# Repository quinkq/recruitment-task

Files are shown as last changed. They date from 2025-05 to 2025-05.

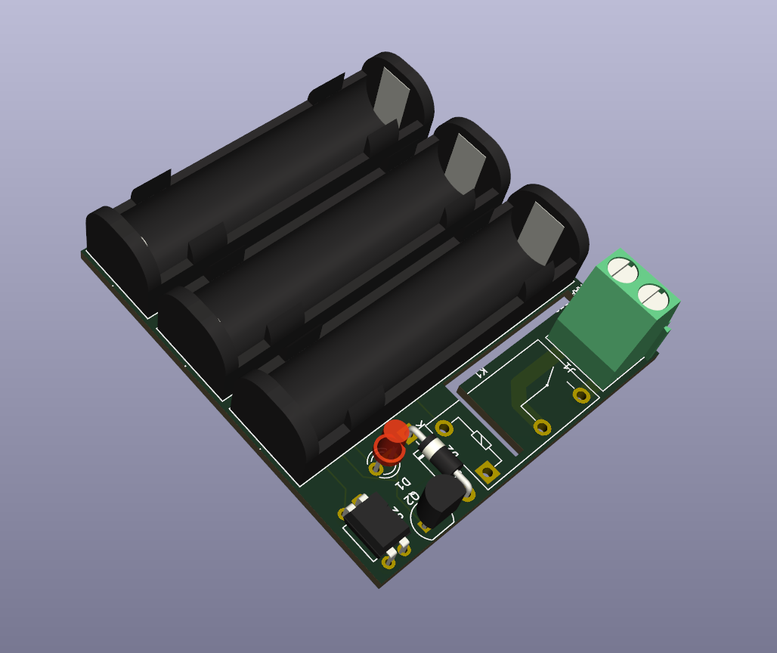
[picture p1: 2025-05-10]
hardware schematics/PCB.png

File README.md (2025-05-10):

Compact, battery-powered electronic device that controls a relay for switching an 110/240 VAC 6A load.

I. Description
This circuit is a compact battery-powered system based on an ATmega328P microcontroller that can monitor battery
voltage, control a relay, and provide user interaction through buttons and status indicators. The design emphasizes low
power consumption with a voltage regulator to provide stable power to the microcontroller.
Power Supply
- Three 1.5V AAA batteries connected in series provide 4.5V input power
- MCP1700 low-dropout regulator (U3) converts the battery voltage to a stable 3.3V for the microcontroller
- Decoupling capacitors (C1, C2, C3, C7) ensure clean power delivery
Microcontroller
- ATmega328P in TQFP package (U1) serves as the main controller
- Reset circuit with push button (SW2) and pull-up resistor (R7) allows for manual resets
- Analog input connected to a voltage divider monitors battery level
- Digital I/O pins control external components
Output Control
- Relay (K1) allows switching of external high-voltage/high-current loads
- Optocoupler (PC817, U2) provides electrical isolation between the microcontroller and relay driver
- NPN transistor (2N3904, Q2) amplifies the control signal to drive the relay coil
- Protection diode (1N4007, D2) prevents inductive kickback when the relay is de-energized
- LED indicator (D1) provides visual status feedback
User Interface
- Push button input (SW1) allows for user interaction
- LED output provides visual feedback on system status

II. Control: Microcontroller ATMEL ATmega328P
1. Low Power
- Active mode: ~5mA at 3.3V, 8MHz
- Power-down sleep mode: <1μA (with proper power management)
- If running at 1MHz, it can drop active current below 1mA.
- Sleep modes allow long battery life
2. Simple and Cheap
- Readily available and has a huge ecosystem of code and libraries.
- Modular
- Cost-efficient.
3. Adequate Performance for the Task
- 10-bit ADC sufficient for battery voltage monitoring.
- Computing power more than sufficient for current project requirements.
- Enough flash and RAM (32KB Flash / 2KB RAM) for basic sensor logging and control logic.
4. Ease of Development and Debugging
- Arduino-compatible for quick prototyping.
- Analog and digital pin flexibility (for sensing battery, controlling relays, etc.) - makes it great choice for further
project adaptations.
- AVR ISP / UPDI flashing - can be pre-programmed before soldering.
In current configuration assuming pulling up unused digital pins and running by using internal oscillator.
Considerations:
STM32L0 series (for example STM32L011K or other low power variant) is a very strong contender for an alternative MCU.
It could offer substantial processing power increase (modern Cortex-M0 32-bit processor), allow for easy integrations if
for example wireless communication was considered for the future, but also opens possibility for even cheaper
components when ordering in bulk/partnering with STM.
If low power chip with integrated Bluetooth LE was a requirement from the start, then nRF52832 is another great option.
Employing wireless functionality in any of these variants would make for an attractive product to compete with SONOFF
products for example.

III. Power source: 3 x AAA batteries + LDO regulator
Due to the requirement of having battery powered controlling device, that will be inherently ineffective when driving a
power-hungry coil of the relay, the simplest solution has been chosen in form of using 3 x AAA batteries. They are
designed to be connected in series, in order to boost voltage to 4.5V, which is then shifted down to MCU and relay
compatible 3.3V level using LDO regulator. Since it’s unlikely that any compact battery will be able to power circuit
satisfying the requirements for more than 7 days, choosing AAA battery was crucial due to ease of their replacement.
1. High popularity and availability
2. Very easy to replace
3. Relatively high capacity, but dependent on the quality of batteries (about 1200 mAh)
4. Enables possibility to commercially distribute the device without batteries (passing this requirement on to the
consumer)
Considerations:
Since this project would likely be used as a device used for switching mains power supply, then most logical would be
adding a switching power supply and filtering its output to power both MCU and relay coil, instead of using batteries.
For more premium devices (relay switching noise unwanted) double MOSFET (totem pole) configuration would be a
great solution, that could be actually run with batteries. If heat dissipation or low volume were critical factors, then it
would still be possible, but would require choosing more high-end MOSFET with lower Rds(on).

IV. Components, calculations, values.
All components have been chosen with the goal of being easily sourceable and replaceable. With further testing
adjustments towards limiting optocoupler and transistor current could and should be made, as that would allow
further energy savings.
Capacitors: All ceramic for decoupling purposes, values according to chip manufacturer’s guidelines.
Resistors: Same principle with exception of:
R2 = 1000 Ohms = 3.3 V / 0.0025 A – limiting current to about 2.5 mA, enough for BJT transistor operation.
R3 = 560 Ohms = 3.3 V / 0.005 A – goal of limiting opto-coupler current down to about 5 mA, to keep small overhead in
case of PC817 current transfer ratio drops.
R4 = 150 Ohms = 3.3 V – 1.2 V / 0.0025 A – goal to maintain about 15mA LED current, assuming standard diode’s 1.2 Vf.
Dependent on final components.
R5 = 36 kOhm R6 = 100kOhm – typical voltage divider for ADC that is designed to take 3.3V as a reference (AREF pin
grounded with C4 capacitor).
Vadc = Vbat × R6/ (R5+R6)
3.3V = 4.5V x R2 / (R5+R6)
R6 / (R5+R6) = 3.3V / 4.5V = 0.733
R6 = 0.733 × (R5+R6)
Designating R6 to be 100 kOhm and solving for R5:
R5 = (100 kOhm / 0.733) − 100kΩ ≈ 36 kOhm

V. Battery life
Assuming high current draw in 30% of the time - device idling (50% of the time) and off time when toggling relay.
ATmega328P Current Consumption
Active Mode (when relay is ON): ~5mA
Sleep Mode (when relay is OFF): ~0.1mA
Relay Consumption
ON (30% of the time): ~20mA – nominal relay current ~ 70mA
OFF (70% of the time): 0mA
Other consumers
Optocoupler + transistor sinking: 7.5mA
Average Current Calculation
(5mA+20mA+7.5mA) × 30% + (0.1mA) × 70% =
= (32.5mA × 30%) + (0.1mA × 70%) =
= 9.75mA + 0.07mA = 9.82 mA
Battery Life (1200mAh AAA in series)
1200 mAh ÷ (~9.82mA) = 122 hours = about 5 days

VI. Costs
Details in BOM.csv.
Estimate for making 5 pieces:
10,16 USD
Estimate for making 1000 pieces:
4,20 USD

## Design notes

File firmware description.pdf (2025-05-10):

## Programming environment:

### VS Code + PlatformiO

Deciding factors:

PlatformIO IDE is a powerful and feature-rich development environment for a larger project that uses the Arduino framework but supports a wider range of microcontroller platforms and development boards, helps maintain better project structure and code maintainability by allowing for proper C++ conventions (separate .h and .cpp files), and offering more efficient debugging and tooling.

## Logic description:

### 1. Setup (setup())

- Initializes serial communication for debugging.
- Configures GPIO pins for button, relay, LED, and battery voltage monitoring.
- Sets button interrupt to wake the device on a press.
- Enters sleep mode immediately after initialization.

### 2. Main Loop (loop())

- Wakes up on button press and processes it (handleButton()).
- If device is ON:
- Checks battery voltage every 5 seconds.
- Toggles relay at the set frequency.
- Updates LED indicator.
- If device is OFF, it enters sleep mode after 500ms.

### 3. Button Handling (handleButton())

- Uses debounce logic to ensure stable button readings.
- Short press toggles the device ON/OFF.
- Long press:
- Adjusts the relay toggle frequency.
- If the button remains pressed, keeps changing frequency at set intervals.

### 4. Changing Relay Frequency (changeFrequency())

- Cycles relay toggle frequency between 1s and 10s.
- Automatically reverses direction when reaching limits (10s -> 9s -> ... -> 1s -> 2s ...).
- LED briefly flashes to indicate a frequency change.

### 5. Relay Toggling (toggleRelay())

- Switches the relay ON/OFF at set intervals.
- Prints status to serial monitor for debugging.

### 6. Battery Monitoring (checkBatteryVoltage())

- Reads voltage using an analog pin.
- Converts ADC value to actual voltage using a voltage divider.
- If voltage < 3.0V, sets lowBatteryDetected = true and starts rapid LED blinking.

### 7. Sleep Mode (enterPowerSavingMode())

- Disables ADC to reduce power consumption.
- Uses SLEEP_MODE_PWR_DOWN to enter sleep.
- Execution halts until button press wakes it up.

### 8. Wake-up Handling (exitPowerSavingMode())

- Re-enables ADC after waking up.
- Ensures the system resumes normal operation.

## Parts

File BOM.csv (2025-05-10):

Reference | Qty | Value | Footprint | Price (1pc) | Sum for (1pc price) | Price (1000pcs) | Sum for (1000pc price) [USD] | Datasheet
AAA-BT1,AAA-BT2,AAA-BT3 | 3 | 1.5V | Battery:BatteryHolder_Keystone_2466_1xAAA | 0,52 | 0,52 | 0,333 | 0,333 | ~
C1,C4,C7 | 3 | 0.1µF | Capacitor_SMD:C_0805_2012Metric | 0,004 | 0,012 | 0,0036 | 0,0108 | ~
C2,C3 | 2 | 1µF | Capacitor_SMD:C_0805_2012Metric | 0,004 | 0,008 | 0,0036 | 0,0072 | ~
D1 | 1 | LED | LED_THT:LED_D3.0mm_FlatTop | 0,02 | 0,02 | 0,018 | 0,018 | ~
D2 | 1 | 1N4007 | Diode_THT:D_DO-41_SOD81_P10.16mm_Horizontal | 0,008 | 0,008 | 0,005 | 0,005 | http://www.vishay.com/docs/88503/1n4001.pdf
J1 | 1 | Screw_Terminal_01x02 | TerminalBlock_Phoenix:TerminalBlock_Phoenix_MKDS-1,5-2_1x02_P5.00mm_Horizontal | 0,0894 | 0,0894 | 0,0591 | 0,0591 | ~
K1 | 1 | G5Q-1A | Relay_THT:Relay_SPST_Omron-G5Q-1A | 0,9036 | 0,9036 | 0,5468 | 0,5468 | https://www.omron.com/ecb/products/pdf/en-g5q.pdf
Q2 | 1 | 2N3904 | Package_TO_SOT_THT:TO-92_Inline | 0,0115 | 0,0115 | 0,0077 | 0,0077 | https://www.onsemi.com/pub/Collateral/2N3903-D.PDF
R2 | 1 | 1k | Resistor_SMD:R_0805_2012Metric | 0,0018 | 0,0018 | 0,0014 | 0,0014 | ~
R3 | 1 | 470 | Resistor_SMD:R_0805_2012Metric | 0,0018 | 0,0018 | 0,0014 | 0,0014 | ~
R4 | 1 | 150 | Resistor_SMD:R_0805_2012Metric | 0,0018 | 0,0018 | 0,0014 | 0,0014 | ~
R5 | 1 | 36k | Resistor_SMD:R_0805_2012Metric | 0,0018 | 0,0018 | 0,0014 | 0,0014 | ~
R6 | 1 | 100k | Resistor_SMD:R_0805_2012Metric | 0,0018 | 0,0018 | 0,0014 | 0,0014 | ~
R7,R8 | 2 | 10k | Resistor_SMD:R_0805_2012Metric | 0,0018 | 0,0036 | 0,0014 | 0,0028 | ~
SW1 | 1 | SW_Push | Button_Switch_SMD:SW_SPST_CK_RS282G05A3 | 0,796 | 0,796 | 0,2918 | 0,2918 | ~
SW2 | 1 | SW_Push | Button_Switch_SMD:SW_SPST_PTS647_Sx70 | 0,1925 | 0,1925 | 0,1243 | 0,1243 | ~
U1 | 1 | ATmega328P-A | Package_QFP:TQFP-32_7x7mm_P0.8mm | 2,1871 | 2,1871 | 1,5494 | 1,5494 | http://ww1.microchip.com/downloads/en/DeviceDoc/ATmega328_P%20AVR%20MCU%20with%20picoPower%20Technology%20Data%20Sheet%2040001984A.pdf
U2 | 1 | PC817 | Package_DIP:DIP-4_W7.62mm | 0,0341 | 0,0341 | 0,0185 | 0,0185 | http://www.soselectronic.cz/a_info/resource/d/pc817.pdf
U3 | 1 | MCP1700x-330xxTT | Package_TO_SOT_SMD:SOT-23 | 0,3705 | 0,3705 | 0,2257 | 0,2257 | http://ww1.microchip.com/downloads/en/DeviceDoc/20001826D.pdf
PCB Manufacturing | 1 |  |  | 5 | 5 | 1 | 1
 |  |  |  |  | Estimate for 5 pcs |  | Estimate for 1000 pcs
 |  |  |  | Total Sum | 10,1683 | USD | 4,2071 | USD

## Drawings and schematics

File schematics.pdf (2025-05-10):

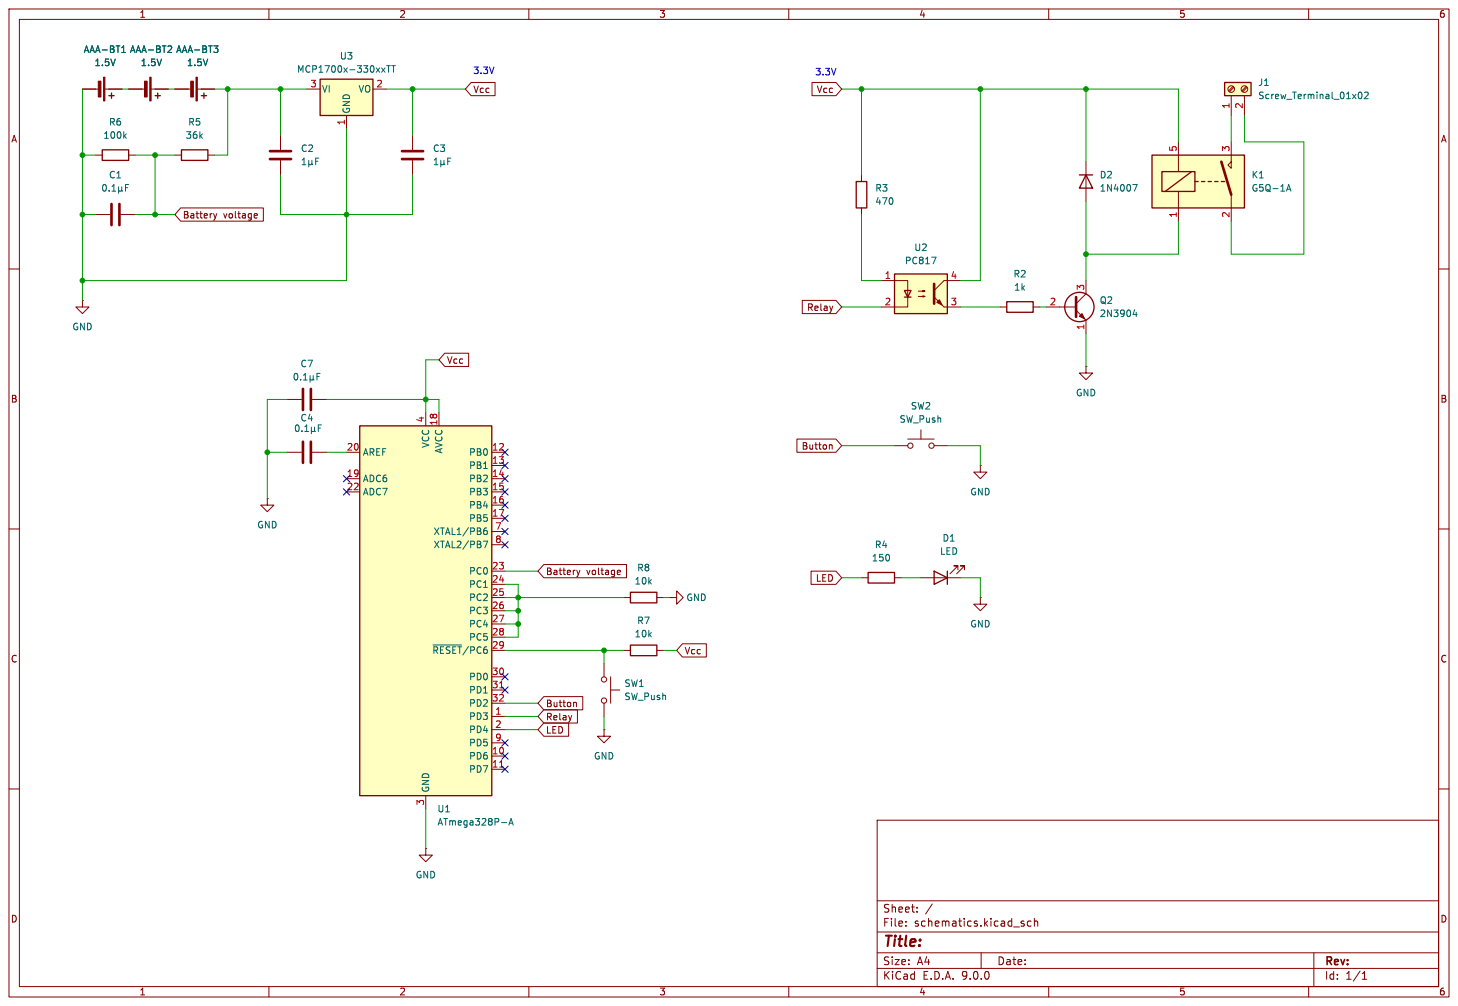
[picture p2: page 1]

Id: 1/1 Title: File: schematics.kicad_sch Sheet: / SW1 SW_Push C7

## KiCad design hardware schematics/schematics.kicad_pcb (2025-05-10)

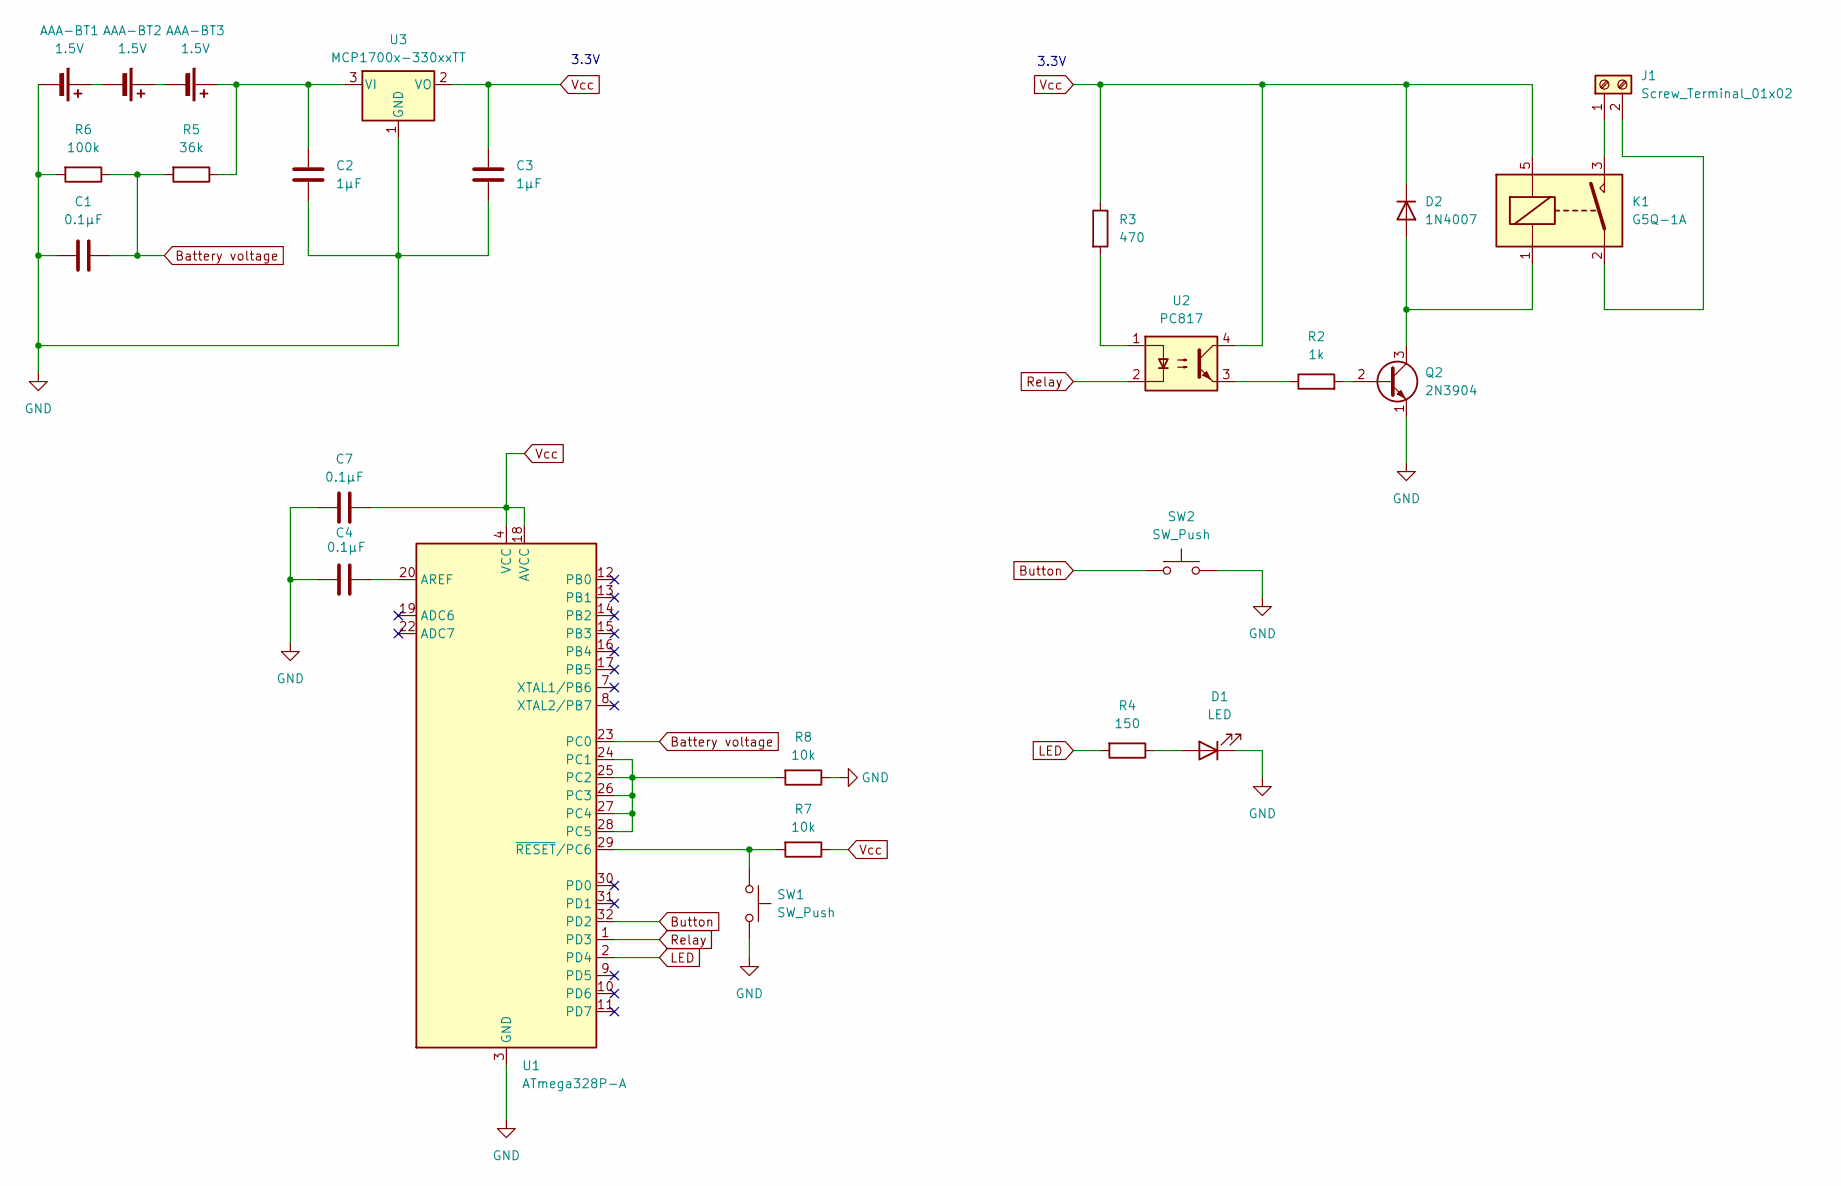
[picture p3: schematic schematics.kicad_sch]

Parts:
AAA-BT1, AAA-BT2, AAA-BT3: 1.5V; BatteryHolder_Keystone_2466_1xAAA
C1, C4, C7: 0.1µF; C_0805_2012Metric
C2, C3: 1µF; C_0805_2012Metric
D1: LED; LED_D3.0mm_FlatTop
D2: 1N4007; D_DO-41_SOD81_P10.16mm_Horizontal
J1: Screw_Terminal_01x02; TerminalBlock_Phoenix_MKDS-1,5-2_1x02_P5.00mm_Horizontal
K1: G5Q-1A; Relay_SPST_Omron-G5Q-1A
Q2: 2N3904; TO-92_Inline
R2: 1k; R_0805_2012Metric
R3: 470; R_0805_2012Metric
R4: 150; R_0805_2012Metric
R5: 36k; R_0805_2012Metric
R6: 100k; R_0805_2012Metric
R7, R8: 10k; R_0805_2012Metric
SW1: SW_Push; SW_SPST_CK_RS282G05A3
SW2: SW_Push; SW_SPST_PTS647_Sx70
U1: ATmega328P-A; TQFP-32_7x7mm_P0.8mm
U2: PC817; DIP-4_W7.62mm
U3: MCP1700x-330xxTT; SOT-23

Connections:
Battery voltage: C1.2, R5.2, R6.1, U1.23 (PC0)
Button: SW2.1, U1.32 (PD2)
GND: AAA-BT1.2 (-), C1.1, C2.1, C3.1, C4.1, C7.1, D1.1 (K), Q2.1 (E), R6.2, R8.1, SW1.2, SW2.2, U1.3 (GND), U1.5 (GND), U1.21 (GND), U3.1 (GND)
LED: R4.2, U1.2 (PD4)
unnamed: AAA-BT1.1 (+), AAA-BT2.2 (-)
unnamed: AAA-BT2.1 (+), AAA-BT3.2 (-)
unnamed: AAA-BT3.1 (+), C2.2, R5.1, U3.3 (VI)
unnamed: D1.2 (A), R4.1
unnamed: D2.2 (A), K1.1, Q2.3 (C)
unnamed: J1.1, K1.3
unnamed: J1.2, K1.2
unnamed: Q2.2 (B), R2.2
unnamed: R2.1, U2.3
unnamed: R3.2, U2.1
unnamed: C4.2, U1.20 (AREF)
unnamed: R8.2, U1.24 (PC1), U1.25 (PC2), U1.26 (PC3), U1.27 (PC4), U1.28 (PC5)
unnamed: R7.2, SW1.1, U1.29 (~RESET/PC6)
Relay: U1.1 (PD3), U2.2
Vcc: C3.2, C7.2, D2.1 (K), K1.5, R3.1, R7.1, U1.4 (VCC), U1.6 (VCC), U1.18 (AVCC), U2.4, U3.2 (VO)

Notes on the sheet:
3.3V

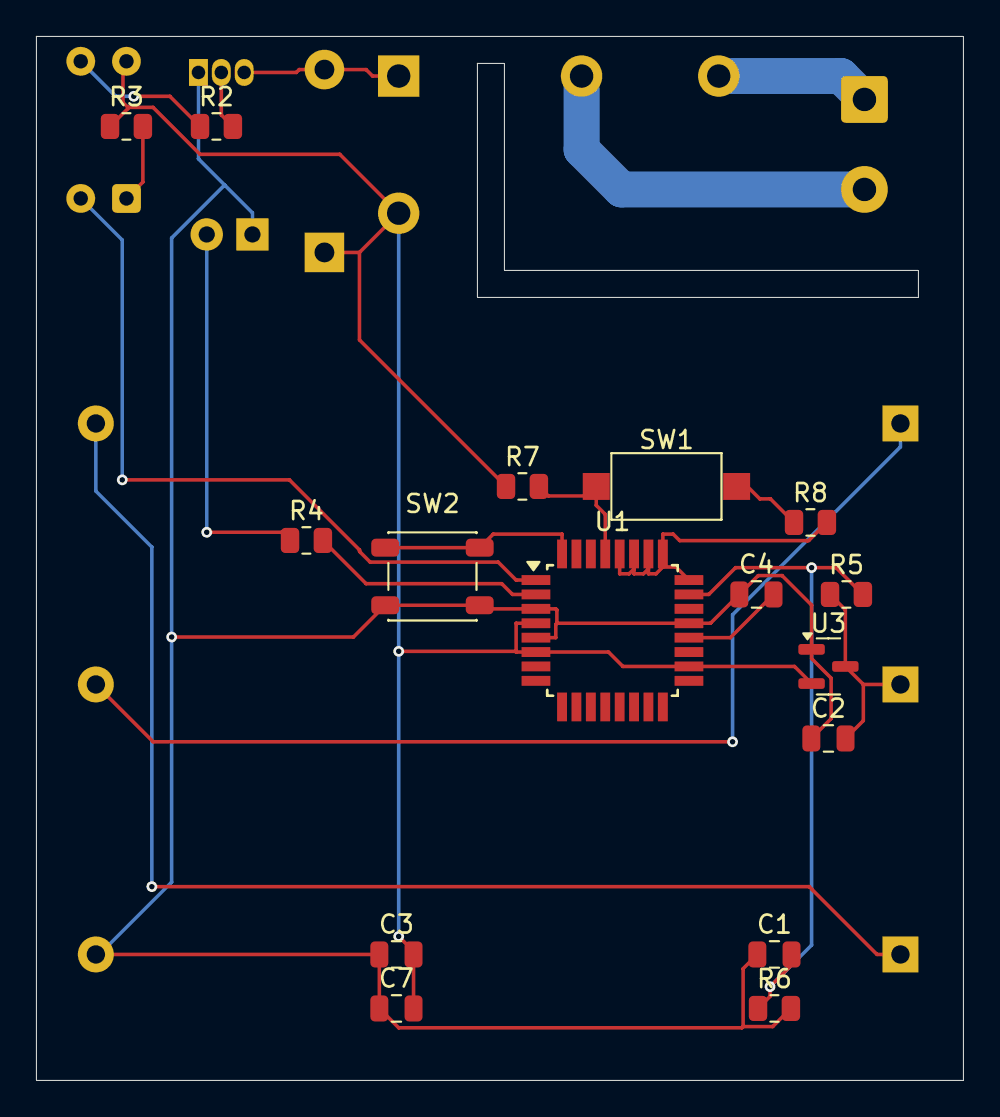
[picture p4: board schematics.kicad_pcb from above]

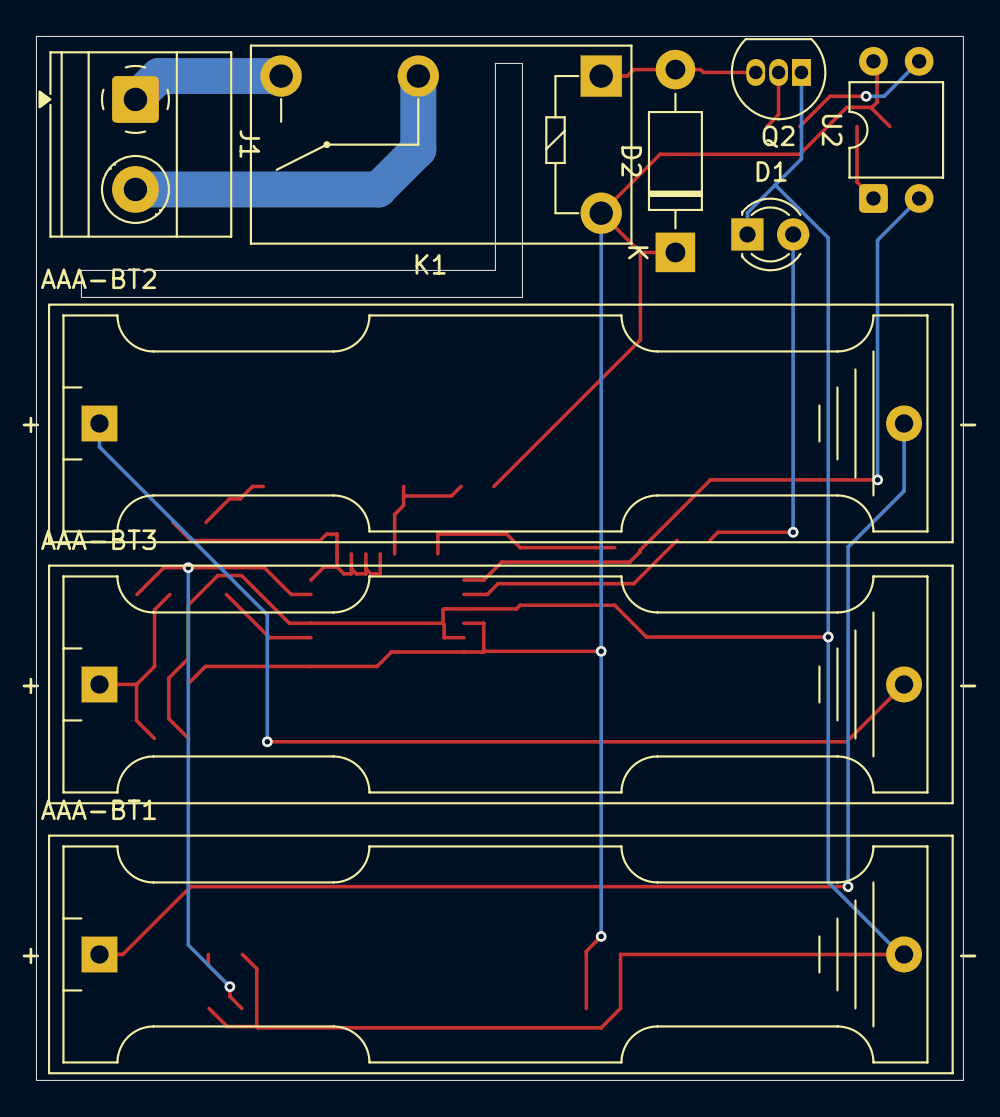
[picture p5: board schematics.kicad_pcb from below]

Board: 2 copper layers, 51.5 x 58.0 mm, 25 parts (9 on the bottom side), 19 nets.

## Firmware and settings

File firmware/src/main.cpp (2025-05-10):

#include <Arduino.h>
#include <avr/sleep.h>
#include <avr/power.h>

// Pin definitions
#define BUTTON_PIN 2       // Push button pin
#define RELAY_PIN 3        // Relay control pin
#define LED_PIN 4          // LED indicator pin
#define BATTERY_PIN A0     // Battery voltage monitoring pin

// Constants
#define DEBOUNCE_DELAY 50          // Button debounce delay in ms
#define LONG_PRESS_DURATION 600    // Duration for long press detection in ms
#define LOW_BATTERY_THRESHOLD 3.0  // Low battery threshold in volts
#define SERIAL_BAUD_RATE 115200    // Serial communication baud rate

// Variables for button state
volatile bool buttonInterruptFlag = false;  // Flag for interrupt
bool lastButtonState = HIGH;                // Previous button state (HIGH = not pressed)
bool currentButtonState = HIGH;             // Current button state
unsigned long lastDebounceTime = 0;         // Last time button state changed
unsigned long buttonPressTime = 0;          // When button was pressed
bool isLongPress = false;                   // Flag for long press detection
bool buttonReleased = true;                 // Flag to detect button release

// Variables for device state
bool deviceOn = false;                  // Device OFF initially
bool frequencyIncrementing = true;      // Direction of frequency change
unsigned int toggleFrequency = 3;       // Relay toggle frequency in seconds
unsigned long lastDeviceToggleTime = 0; // Last time device was toggled
unsigned long lastToggleTime = 0;       // Last time relay was toggled
bool relayState = HIGH;                 // Current relay state (LOW = relay energized/ON, HIGH = relay OFF)
bool lowBatteryDetected = false;        // Low battery flag
unsigned long lastBatteryCheckTime = 0; // Last battery check time
unsigned long lastBlinkTime = 0;        // For LED blinking
volatile bool wakeUpFlag = false;       // Flag to indicate waking from sleep

// Declarations
void toggleDevice(bool forceRelayActivation = false);
void toggleRelay();
void handleButton();
void changeFrequency();
void updateLEDIndicator();
void checkBatteryVoltage();
void enterPowerSavingMode();
void exitPowerSavingMode();

// Interrupt service routine - handle button presses for wakeups
void buttonISR() {
  buttonInterruptFlag = true;
  if (!deviceOn) {
    wakeUpFlag = true; // Set flag to indicate we're waking from sleep
  }
  sleep_disable(); // Wake up from sleep immediately
}



void setup() {
  // Initialize serial for debugging
  Serial.begin(SERIAL_BAUD_RATE);
  Serial.println(F("Relay Controller Starting..."));
  
  // Initialize pins
  pinMode(RELAY_PIN, OUTPUT);
  pinMode(LED_PIN, OUTPUT);
  pinMode(BUTTON_PIN, INPUT_PULLUP);
  pinMode(BATTERY_PIN, INPUT);
  
  // Initialize outputs - Start with device OFF
  digitalWrite(RELAY_PIN, HIGH);  // Relay is OFF when HIGH
  digitalWrite(LED_PIN, LOW);     // LED is OFF initially
  
  // Setup button interrupt
  attachInterrupt(digitalPinToInterrupt(BUTTON_PIN), buttonISR, FALLING);
  
  Serial.println(F("System initialized. Device OFF."));
  
  // Enter sleep mode immediately after initialization
  delay(100); // Delay for serial output to complete
  enterPowerSavingMode();
}

void loop() {
  // Check if woken up by interrupt
  if (buttonInterruptFlag) {
    delay(50);  // Another debounce
    buttonInterruptFlag = false;
    
    // If we were in sleep mode and this is a wake-up event
    if (wakeUpFlag) {
      wakeUpFlag = false;
      toggleDevice(true); // Force relay activation on wake-up
      delay(100); // Delay to stabilize
    }
  }
  
  // Process button input
  handleButton();
  
  // If device is on handle relay toggle and battery monitoring
  if (deviceOn) {
    // Check battery voltage every 60 seconds (ORIGINALLY 5s - that's what description says)
    if (millis() - lastBatteryCheckTime >= 60000) {
      checkBatteryVoltage();
      lastBatteryCheckTime = millis();
    }
    
    // Handle relay toggling based on frequency
    if (millis() - lastToggleTime >= (toggleFrequency * 1000)) {
      toggleRelay();
      lastToggleTime = millis();
    }
    
    // Handle LED indicators
    updateLEDIndicator();
    
  // If Device off, go to sleep
  } else { 
    // Only enter sleep mode if device was toggled more than 500ms ago to avoid immediately going back to sleep after wakeup
    if (millis() - lastDeviceToggleTime > 500) {
      enterPowerSavingMode();
    }
  }
}

void handleButton() {
  // Read the button state
  int reading = digitalRead(BUTTON_PIN);
  
  // Check if button state changed
  if (reading != lastButtonState) {
    lastDebounceTime = millis();
  }
  
  // If button state is stable (debounced)
  if ((millis() - lastDebounceTime) > DEBOUNCE_DELAY) {
    // If button state has changed
    if (reading != currentButtonState) {
      currentButtonState = reading;
      
      // Button pressed (LOW when pressed due to INPUT_PULLUP)
      if (currentButtonState == LOW && buttonReleased) {
        buttonPressTime = millis();
        buttonReleased = false;
        isLongPress = false;
        
        Serial.println(F("Button pressed"));
      }
      
      // Button released
      else if (currentButtonState == HIGH && !buttonReleased) {
        // Check if it was a short press (for toggling device ON/OFF)
        if (!isLongPress && (millis() - buttonPressTime < LONG_PRESS_DURATION) && !wakeUpFlag) {
          toggleDevice();
          Serial.println(F("Short press detected - Toggling device"));
        } else {
          Serial.println(F("Long press ended"));
        }
        
        buttonReleased = true;
        isLongPress = false;
      }
    }
  }
  
  // Check for long press (for changing frequency)
  if (currentButtonState == LOW && !buttonReleased && !isLongPress) {
    if (millis() - buttonPressTime >= LONG_PRESS_DURATION) {
      isLongPress = true;
      changeFrequency();
      Serial.println(F("Long press detected - Changing frequency"));
    }
  }
  
  // Continue to change frequency with button is held
  if (isLongPress && (millis() - buttonPressTime) % LONG_PRESS_DURATION == 0) {
    changeFrequency();
  }
  
  lastButtonState = reading;
}

// Toggle device state (ON/OFF)
void toggleDevice(bool forceRelayActivation) {
  lastDeviceToggleTime = millis();
  
  deviceOn = !deviceOn;
  
  if (deviceOn) {
    Serial.println(F("Device turned ON"));
    
    // Exit power saving mode
    exitPowerSavingMode();
    
    // Reset timers
    lastBatteryCheckTime = millis();
    checkBatteryVoltage(); // Check battery right away
    
    // Handle relay state on turn-on
    if (forceRelayActivation) {
      // Immediately activate relay when turning on
      relayState = LOW; // LOW = relay ON
      digitalWrite(RELAY_PIN, relayState);
      Serial.println(F("Relay activated on device startup"));
    } else {
      // Start with relay off, will toggle according to timing
      relayState = HIGH; // HIGH = relay OFF
      digitalWrite(RELAY_PIN, relayState);
    }
    
    // Reset toggle timer AFTER setting relay state
    lastToggleTime = millis();
    
  } else {
    Serial.println(F("Device turned OFF"));
    
    // Turn off relay and LED when device is off
    relayState = HIGH;  // HIGH = relay OFF
    digitalWrite(RELAY_PIN, HIGH);
    digitalWrite(LED_PIN, LOW);
    
    Serial.println(F("Relay forced OFF"));
  }
}

void changeFrequency() {
  // Flash LED to indicate frequency change
  digitalWrite(LED_PIN, LOW);
  delay(50);
  digitalWrite(LED_PIN, HIGH);
  delay(50);
  digitalWrite(LED_PIN, LOW);  
  
  // Change frequency value (cycling between 1 and 10)
  if (frequencyIncrementing) {
    toggleFrequency++;
    if (toggleFrequency >= 10) {
      frequencyIncrementing = false;
    }
  } else {
    toggleFrequency--;
    if (toggleFrequency <= 1) {
      frequencyIncrementing = true;
    }
  }
  
  Serial.print(F("Toggle frequency changed to: "));
  Serial.print(toggleFrequency);
  Serial.println(F(" second(s)"));
}

void toggleRelay() {
  // Toggle relay state (HIGH = relay OFF, LOW = relay ON)
  relayState = !relayState;
  digitalWrite(RELAY_PIN, relayState);
  
  Serial.print(F("Relay toggled to: "));
  Serial.println(relayState ? F("OFF (Open)") : F("ON (Closed)"));
}

void updateLEDIndicator() {
  // Handle low battery blinking
  if (lowBatteryDetected) {
    // Quick blinking for low battery (200ms on, 200ms off)
    if (millis() - lastBlinkTime >= 200) {
      digitalWrite(LED_PIN, !digitalRead(LED_PIN));
      lastBlinkTime = millis();
    }
  } else {
    // LED follows relay state (LED is ON when relay is ON)
    digitalWrite(LED_PIN, !relayState);
  }
}

void checkBatteryVoltage() {
  // Read battery voltage
  int rawValue = analogRead(BATTERY_PIN);
  
  // Calculate voltage (with voltage divider factor of 2 - 100k/100k ohm divider)
  float voltage = ((rawValue / 1023.0) * 5.0) * 2;
  
  Serial.print(F("Battery voltage: "));
  Serial.print(voltage, 2);
  Serial.println(F("V"));
  
  // Check if battery is low
  if (voltage < LOW_BATTERY_THRESHOLD) {
    if (!lowBatteryDetected) {
      Serial.println(F("WARNING: Low battery detected!"));
      lowBatteryDetected = true;
    }
  } else {
    if (lowBatteryDetected) {
      Serial.println(F("Battery level normal"));
      lowBatteryDetected = false;
    }
  }
}

void enterPowerSavingMode() {
  Serial.println(F("Entering sleep mode..."));
  delay(100); // Give serial time to send
  
  // Disable ADC to save power
  ADCSRA &= ~(1 << ADEN);
  
  // Configure sleep mode
  set_sleep_mode(SLEEP_MODE_PWR_DOWN);
  
  // Enable sleep mode
  sleep_enable();
  
  // Put the device to sleep
  sleep_mode();
  
  // Code execution continues here after wake-up
  
  // Disable sleep mode after waking up
  sleep_disable();
  
  Serial.println(F("Woke up from sleep mode"));
}

void exitPowerSavingMode() {
  // Re-enable ADC
  ADCSRA |= (1 << ADEN);
  
  Serial.println(F("Power saving mode exited"));
}
